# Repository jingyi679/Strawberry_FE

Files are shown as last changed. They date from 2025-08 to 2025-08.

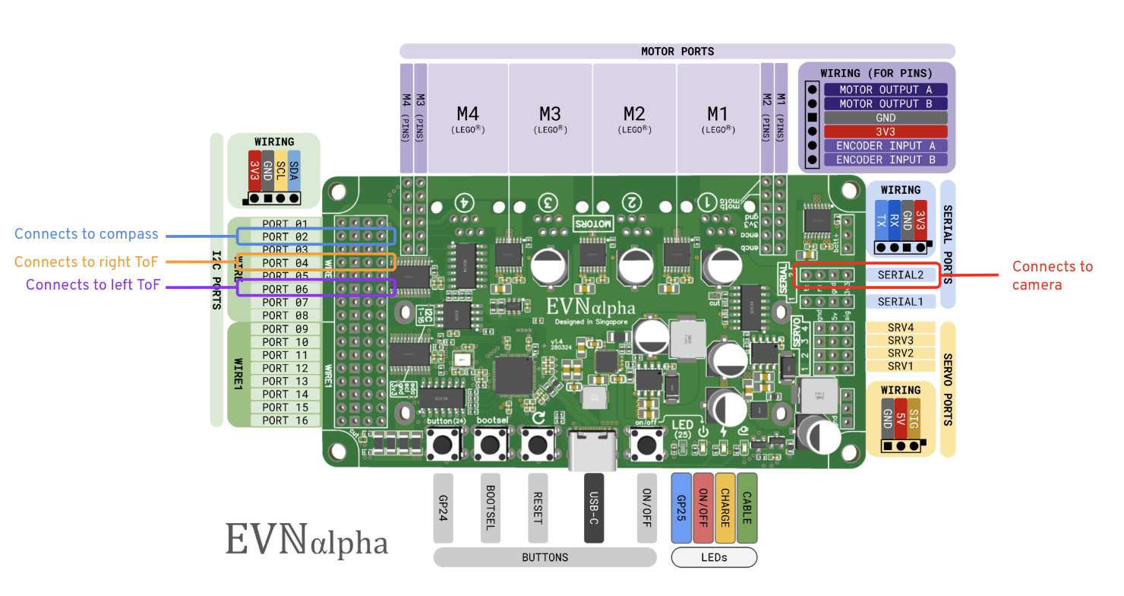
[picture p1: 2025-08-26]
schemes/Simple wiring diagram to EVN.png

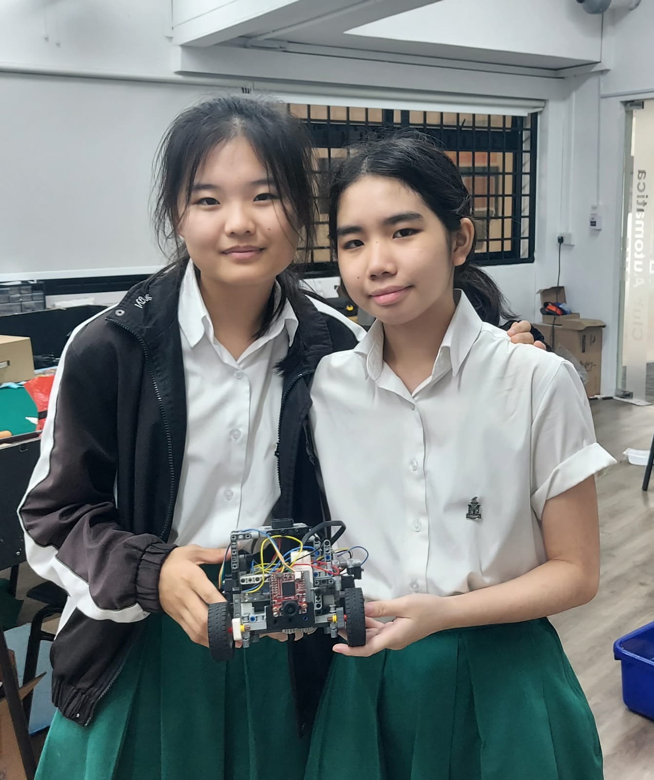
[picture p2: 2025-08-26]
t-photos/WRO FE Strawberry team photo.jpeg

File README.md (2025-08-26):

# WRO 2025 Future Engineers

### Team information: 
Team name: Strawberry

Team ID: FE-25-295-01

Team members: Ge Jingyi (in charge of software) and Katelyn Kang (in charge of hardware)

### Contents: 

`t-photos` contains our team photo

`v-photos` contains photos of our robot 
  
  `top.jpg`
  
  `bottom.jpg`
  
  `left.jpg`
  
  `right.jpg`
  
  `front.jpg`
  
  `back.jpg`

`video` contains both the .mp4 file of our video and the link to it on YouTube 

`schemes` contains wiring diagrams for our robot

`src` contains the source code used

`models` contains all the .stl files for all of the 3D-printed parts of our robot and the technical drawings for each part (HMC5883L mount, OpenMV H7 mount, VL53L0X mount)

`doc` contains our documentation in pdf form 

### Overview: 

Welcome to Team Strawberry’s github repository for WRO Future Engineers 2025. This README provides a simple overview of our robot. For more information, please refer to our documentation which can be found under /doc or can be accessed via this pdf: https://drive.google.com/file/d/1Vhu3sat-Zx_eqKWrcASS5R9QDsB3pyeH/view?usp=sharing   

### Challenge overview: 

For WRO FE, the challenge is split into two rounds – the open round and the obstacle round. In the open round, the robot is required to drive 3 rounds around the game field before coming to a stop in the starting area. For the obstacle round, the robot also has to navigate through the green and red obstacles – turning to the left to go around the obstacle when it is green and to the right when it is red. 

### Robot photos

They are in the `v-photos` folder. They can also be accessed here: 
https://drive.google.com/drive/folders/1iPZja8Sno2P24jc1DyQ11vu2lhnCgzWN?usp=sharing 

### Demo videos

The videos can be found on both this github repository and on YouTube. For the github, we have uploaded the .mp4 video of our robot runs under the `videos` folder. For YouTube, we have uploaded the videos and they can be accessed using the following link: https://youtu.be/RUq1AFjBJ5Y 

### Hardware overview: 

Parts used: 

1x EVN Alpha

2x 18650 Lithium ion batteries

2x LEGO EV3 Medium motors (45503)

2x VL52L0X ToF distance sensors 

1x OpenMV H7 Camera

1x HMC5883L Compass/ Magnetometer

Female to female jumper wires 

3D printed parts 

Various lego pieces 

For our robot chassis, we primarily used lego to build it. Our robot uses rear-wheel drive. The front wheels are used to control the robot’s direction while the back wheels are powered by a motor. This is because rear-wheel drive would provide better stability and control as compared to front-wheel drive. 
The back wheels are both connected to the same motor but using a lego differential gear, due to the rule that the 2 back wheels cannot be connected to different motors. Using a differential gear would allow each of the back wheels to turn at different speeds despite being connected to the same motor, hence allowing the robot to turn. 
The front wheels, which are used to control the robot’s steering, uses Ackermann steering. This would reduce the front wheel slipping. If the 2 front wheels were to be parallel when turning, the wheels would slip because the center of rotation for each wheel would be different. Hence, Ackermann steering was used to allow the inner wheel to turn more, preventing the wheels from slipping. 
For the sensors, our robot uses various non-lego sensors, such as VL53L0X ToFs, a camera etc. Hence, to securely connect these non-lego sensors to our robot chassis made up of lego, we have designed and 3D-printed our own mounts for each sensor. The mounts have holes to screw the non-lego sensors into and for lego technic pegs so that we could attach them to the robot using lego. The stl files for each mount can be found on our github under the `models` folder.

### Software overview: 
All of our source code has been uploaded to this github repository and can be found under the `src` folder. 

Open round: 

For the open round, we initially wanted the robot to use the robot’s ToFs to find the robot’s distance from the outer and inner walls. From there, we would use PID (Proportional Integral Derivative) to ensure that the robot would stay a fixed distance away from the inner wall, hence allowing the robot to follow the inner wall and go around the field. However, we found that this could lead to some problems, such as the robot starting to spin due to an awkward position of the ToF sensor causing it to detect a much larger distance from the wall. 

Hence, we decided to also use a compass, which would allow us to also know the robot’s orientation. A PID controller was then applied to the compass readings to stabilise orientation, while the ToFs provided corrective adjustments to ensure the robot maintained an appropriate trajectory. 

Obstacle round: 

For the detection of the obstacles, we used our OpenMV camera. We used the ‘find_blobs()’ function to detect the red and green pillars as blobs. The camera would then be able to find the positions of the red and green pillars, and would hence send this information to the EVN via serial. This would then be used to determine how much the robot is supposed to turn to avoid the obstacle.

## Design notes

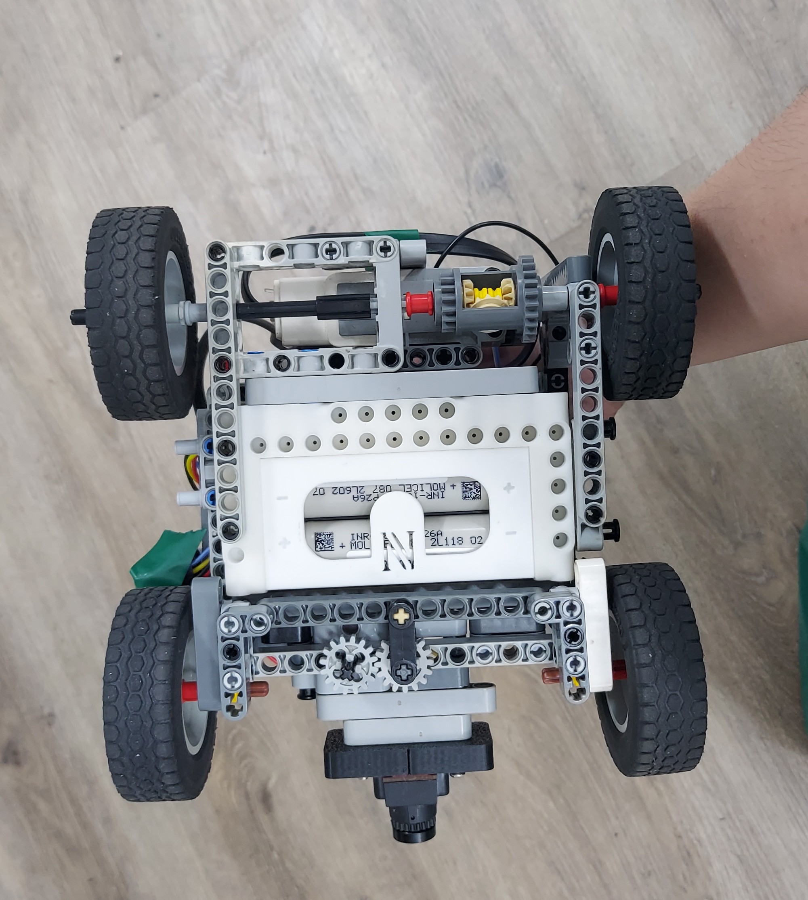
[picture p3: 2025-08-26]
v-photos/bottom.jpg

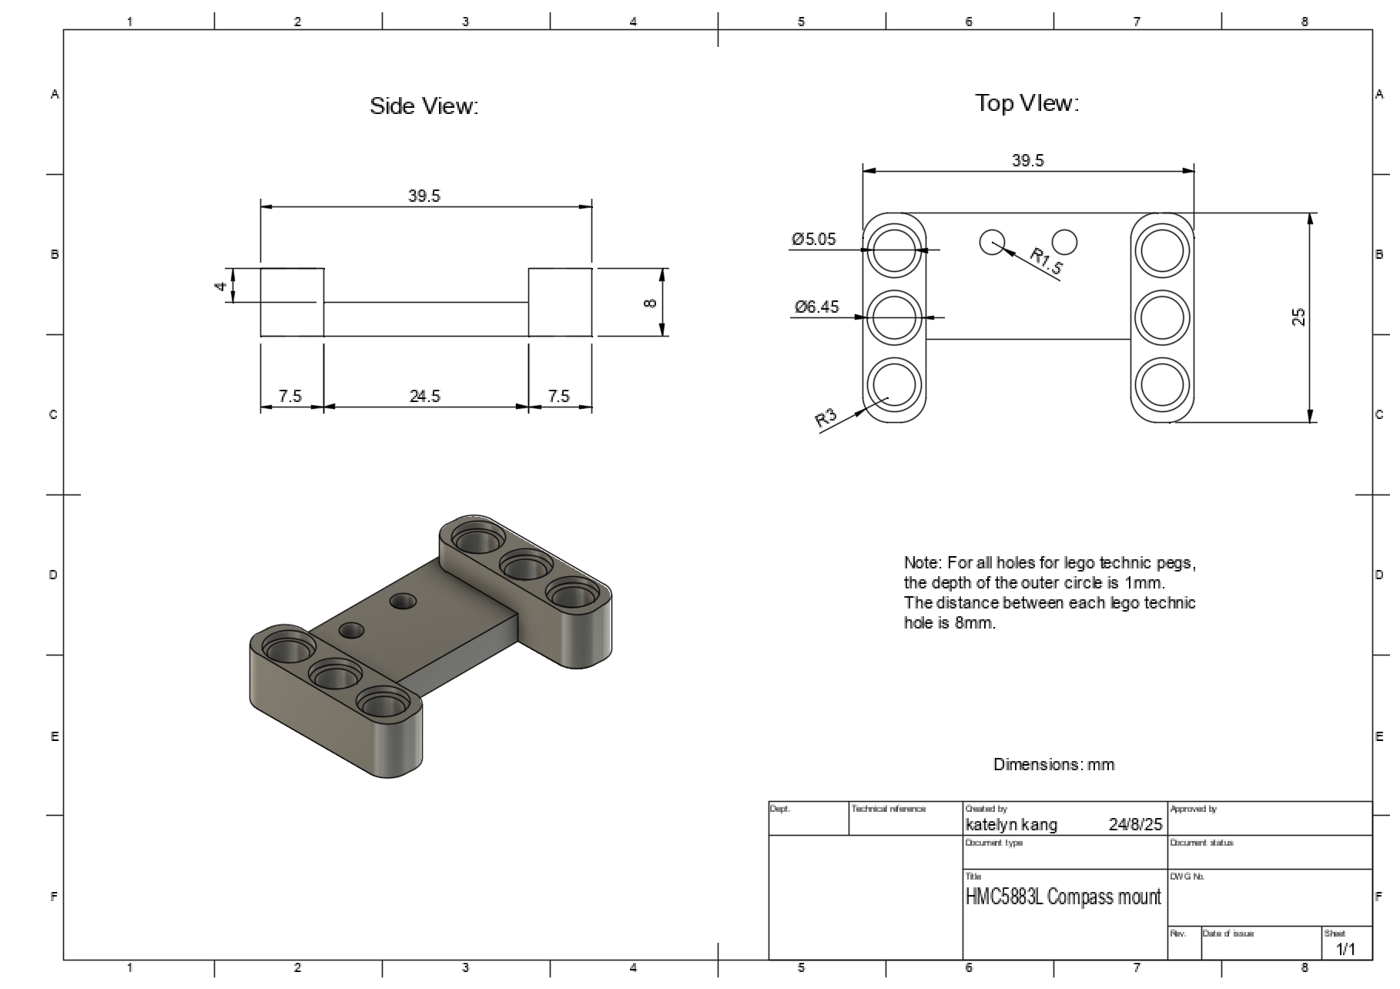
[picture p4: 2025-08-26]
models/HMC5883L mount technical drawing.png

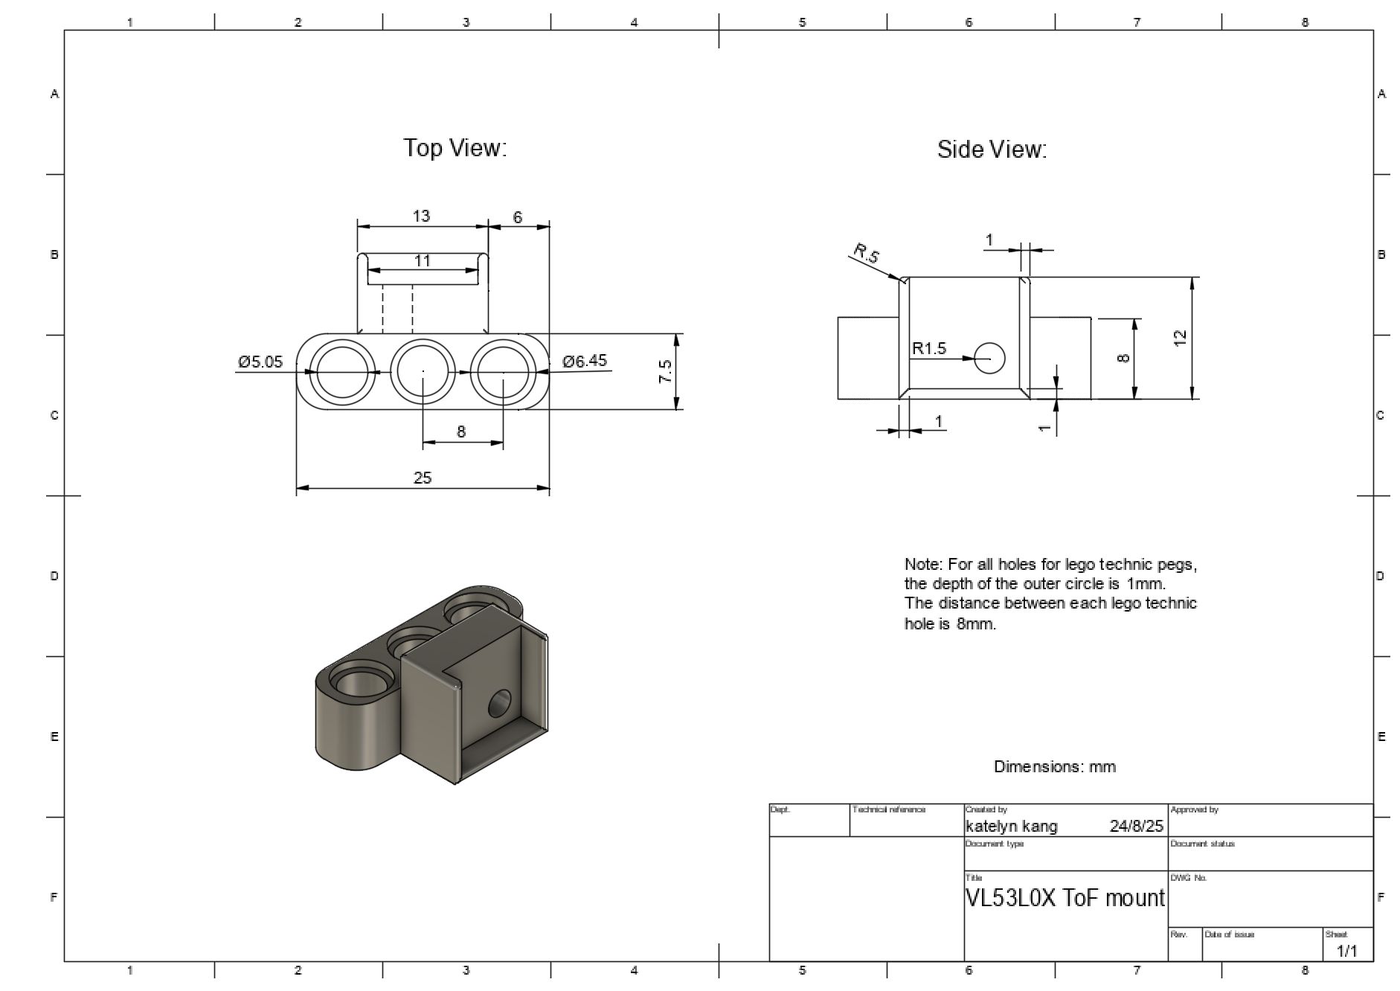
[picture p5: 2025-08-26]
models/VL53L0X Mount technical drawing.png

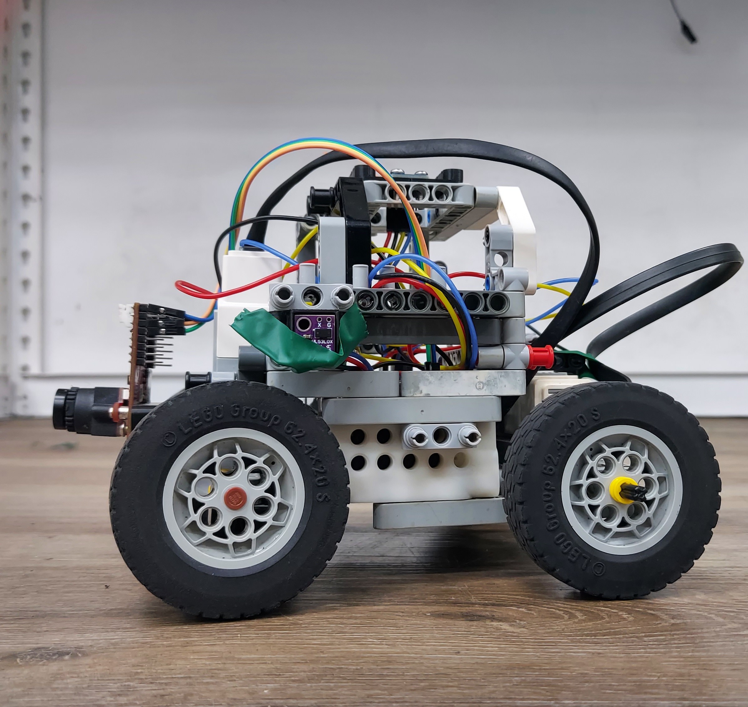
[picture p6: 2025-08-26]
v-photos/left.jpg

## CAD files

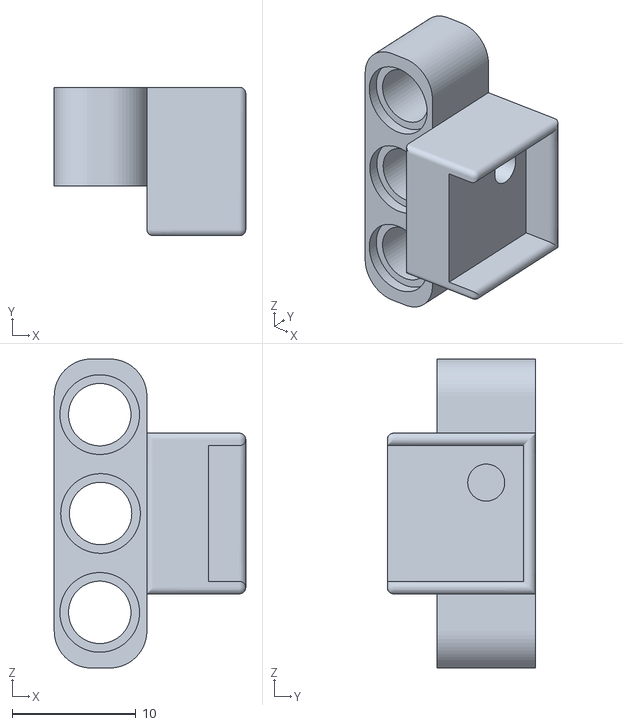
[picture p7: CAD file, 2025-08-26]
models/VL53L0X ToF mount.stl
15.5 x 12.0 x 25.0

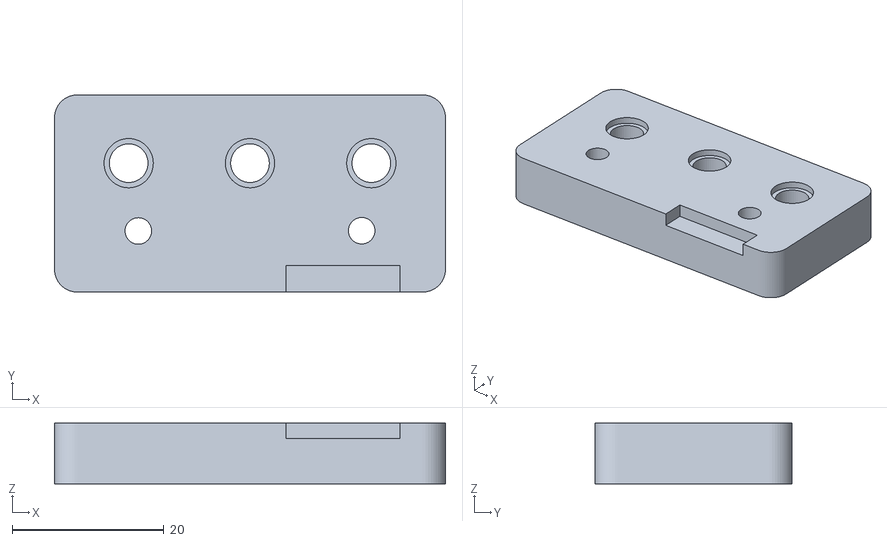
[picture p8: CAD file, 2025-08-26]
models/OpenMV H7 Camera mount.stl
51.6 x 26.0 x 8.00

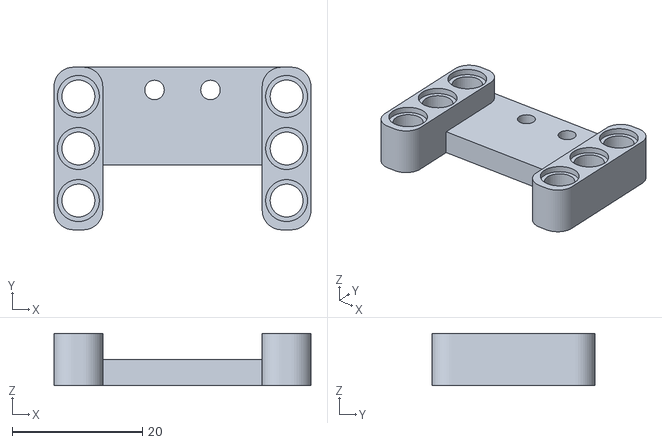
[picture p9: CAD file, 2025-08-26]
models/HMC5883L compass mount.stl
39.5 x 25.0 x 8.00

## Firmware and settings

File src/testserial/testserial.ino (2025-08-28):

#include <EVN.h>

EVNAlpha board;
EVNMotor backmotor(3, EV3_MED);
EVNMotor frontmotor(1, EV3_MED);
EVNDistanceSensor righttof(5, 33);
EVNDistanceSensor lefttof(8, 33);
float Kp = 0.5;

void setup() {
    board.begin();
    Serial.begin(115200);
    Serial2.begin(9600);
    delay(1000);
    righttof.begin();
    lefttof.begin();
}

void setup1() {
    backmotor.begin();
    frontmotor.begin();
}

void loop() {
    // uint16_t rightdist = righttof.read(true);
    // uint16_t leftdist = lefttof.read(true);
    // Serial.println("righttof: ");
    // Serial.println(rightdist);
    // Serial.println(" mm");

    // Serial.println("lefttof: ");
    // Serial.println(leftdist);
    // Serial.println(" mm");
     if (Serial2.available()) {
        int incomingChar = Serial2.read();
        Serial.println(incomingChar, DEC);
        // Serial.println("something");
      }
      else {
        Serial.println("nothing");
      }
      delay(1000);

      //for test code, it should just print 0 
}

//positive angle, turn right
//negative anle, turn left 
// void jajaj() {
//     uint16_t rightdist = righttof.read(true);
//     uint16_t leftdist = lefttof.read(true);
//     int error = rightdist - leftdist; // if neg, then closer to rightwall
//     int steer = Kp*error;
//     // if (steer > 20) {
//     //     steer = 20;
//     // }
//     // if (steer < -20) {
//     //     steer = -20;
//     // }
//     Serial.println(steer);
//     // frontmotor.runPosition(300,steer, false);
// }

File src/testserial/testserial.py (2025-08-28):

# This work is licensed under the MIT license.
# Copyright (c) 2013-2023 OpenMV LLC. All rights reserved.
# https://github.com/openmv/openmv/blob/master/LICENSE
#
# Hello World Example
#
# openmv_brick_detection.py

import sensor, image, time
import pyb
from pyb import UART

sensor.reset()
sensor.set_pixformat(sensor.RGB565)
sensor.set_framesize(sensor.QVGA)
sensor.skip_frames(time = 2000)
sensor.set_auto_gain(True)
sensor.set_auto_whitebal(True)

clock = time.clock()

COLOR_THRESHOLDS = [
    (20, 40, 30, 50, 25, 50), # Red threshold (RGB: R_min, R_max, G_min, G_max, B_min, B_max)
    (25, 45, -50, -20, 10, 32) # Green threshold (LAB: L_min, L_max, A_min, A_max, B_min, B_max)
]

RED_COLOR = (255, 0, 0)
GREEN_COLOR = (0, 255, 0)
TEXT_COLOR = (255, 255, 255) # White text for contrast, though not used for "Unknown" anymore
uart = UART(3, 9600)
blue_led = pyb.LED(3)

while(True):
    uart.write(bytearray([0]))
    #basically the code just sends '0' to the evn
    #this code is just to test whether the serial works
    #like if the connections and stuff are correct
    #it doesnt send the actual obstacle stuff yet

    blue_led.on() #easier debugging because can tell if the code is running from the blue led
#    time.sleep(1000)
    clock.tick()
    img = sensor.snapshot()

    screen_midpoint_x = img.width() // 2

    img.draw_line(screen_midpoint_x, 0, screen_midpoint_x, img.height(), color=(255, 255, 255), thickness=1)

    blobs = img.find_blobs(COLOR_THRESHOLDS, pixels_threshold=200, area_threshold=200, merge=True)

    if blobs:
        for blob in blobs:
            center_x = blob.cx()

            # Initialize color_name and draw_color based on the detected blob's code.
            # Since blobs are only found if they match a threshold, these will always be set.
            color_name = "" # Will be set to "Red" or "Green"
            draw_color = (0, 0, 0) # Will be set to RED_COLOR or GREEN_COLOR

            if blob.code() & 0b001: # Checks if the first threshold (Red) was matched
                color_name = "Red"
                draw_color = RED_COLOR
            if blob.code() & 0b010: # Checks if the second threshold (Green) was matched
                color_name = "Green"
                draw_color = GREEN_COLOR

            side_of_screen = ""
            if center_x < screen_midpoint_x:
                side_of_screen = "Left side"
            else:
                side_of_screen = "Right side"

            img.draw_rectangle(blob.rect(), color=draw_color, thickness=2)
            img.draw_cross(center_x, blob.cy(), color=draw_color, size=10)
            img.draw_string(blob.x(), blob.y() - 10, "%s (%s)" % (color_name, side_of_screen), color=draw_color, scale=1.5)
            print("%s brick detected on the %s" % (color_name, side_of_screen))

    else:
        print("No bricks detected.")

    print("FPS: %f" % clock.fps())

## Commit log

2025-08-26 Uploaded compass mount
    [HMC5883L compass mount.stl]
2025-08-26 Uploaded camera mount
    [OpenMV H7 Camera mount.stl]
2025-08-26 Uploaded new ToF mount
    [VL53L0X ToF mount.stl]
2025-08-26 Uploaded technical drawings for the various mounts
2025-08-26 Uploaded wiring diagrams
2025-08-26 Correct camera mount dimensions
2025-08-28 Uploaded test serial code
    This code is just to see if your serial works it doesnt actually do anything just checks if the evn can even receive anything from camera
